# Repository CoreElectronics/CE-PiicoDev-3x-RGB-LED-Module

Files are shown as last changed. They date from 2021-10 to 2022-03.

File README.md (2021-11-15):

# PiicoDev® 3x RGB LED Module Hardware Repo


This is the repo for the Core Electronics [PiicoDev 3x RGB LED Module](https://core-electronics.com.au/catalog/product/view/sku/CE07910).

## License
This project is open source - please review the LICENSE.md file for further licensing information.

If you have any technical questions, or concerns about licensing, please contact technical support on the [Core Electronics forums](https://forum.core-electronics.com.au/).

*\"PiicoDev\" and the PiicoDev logo are trademarks of Core Electronics Pty Ltd.*

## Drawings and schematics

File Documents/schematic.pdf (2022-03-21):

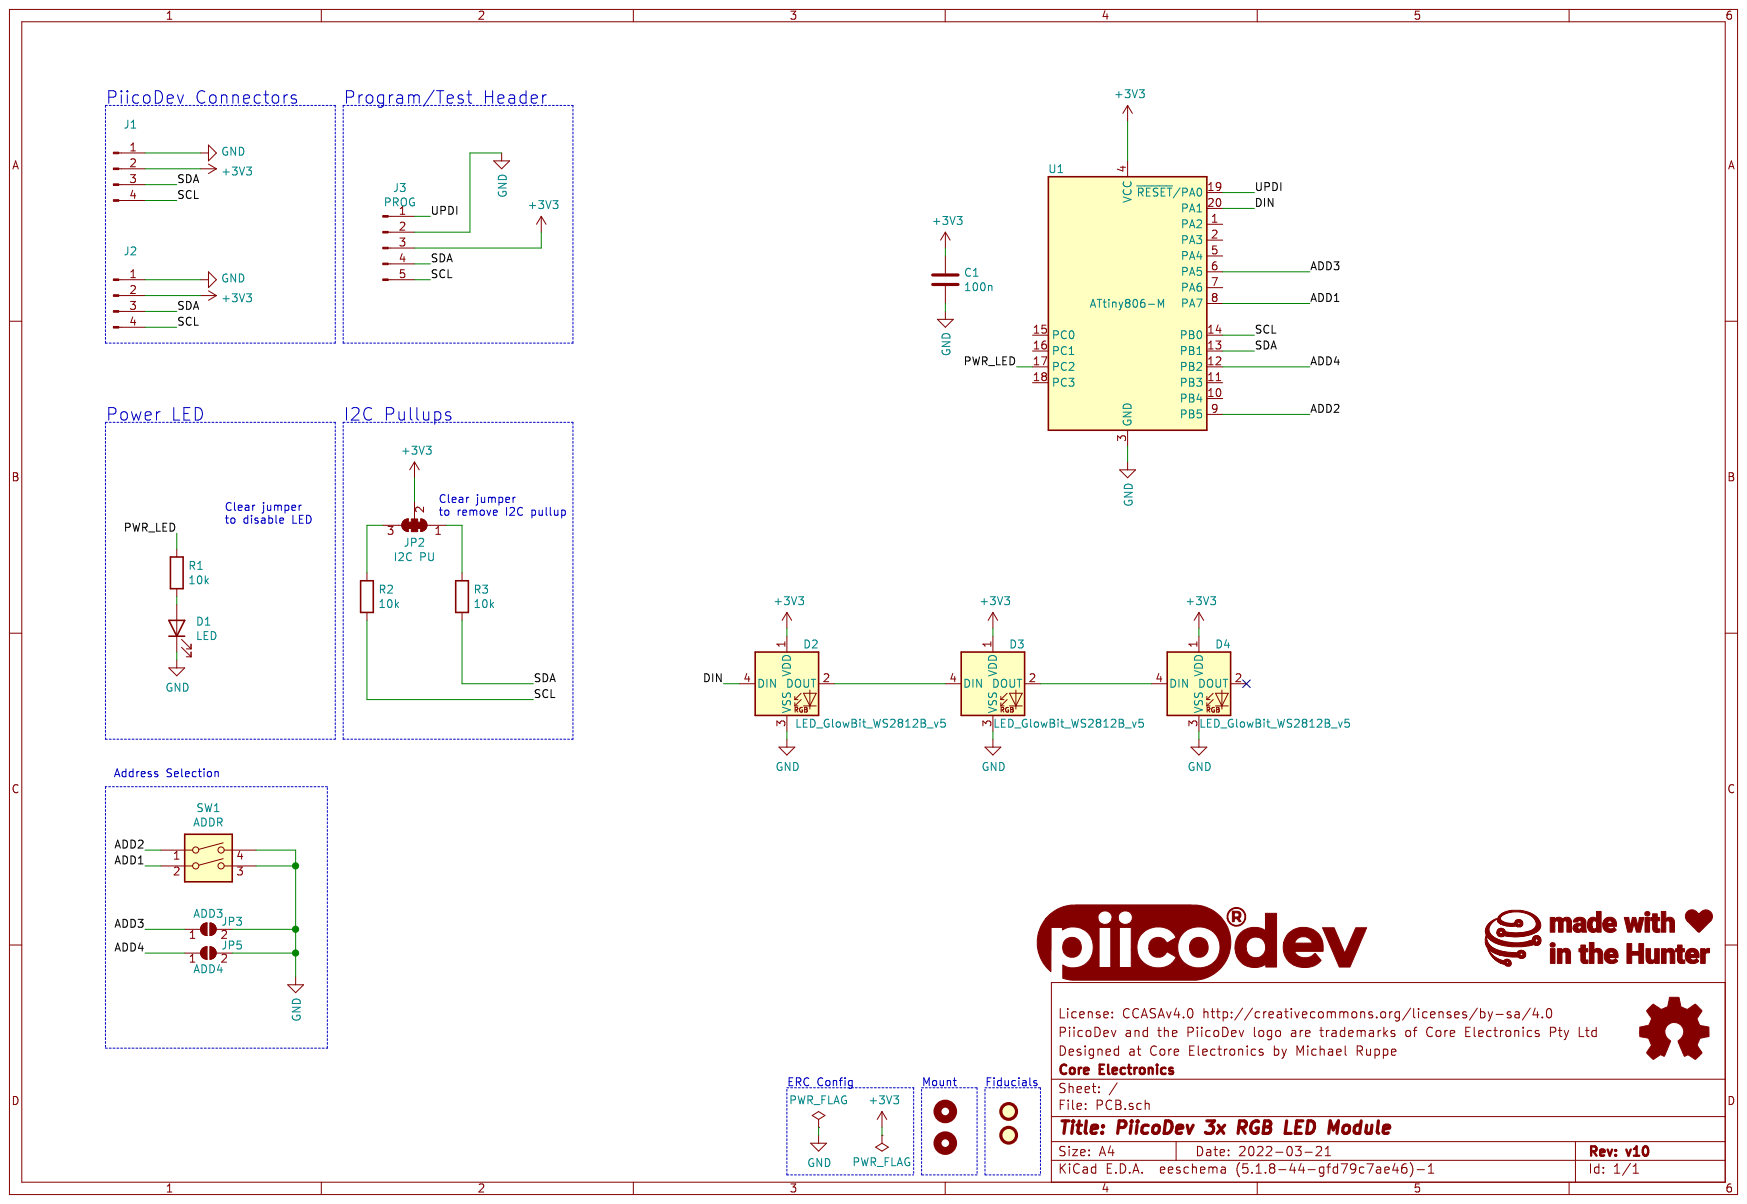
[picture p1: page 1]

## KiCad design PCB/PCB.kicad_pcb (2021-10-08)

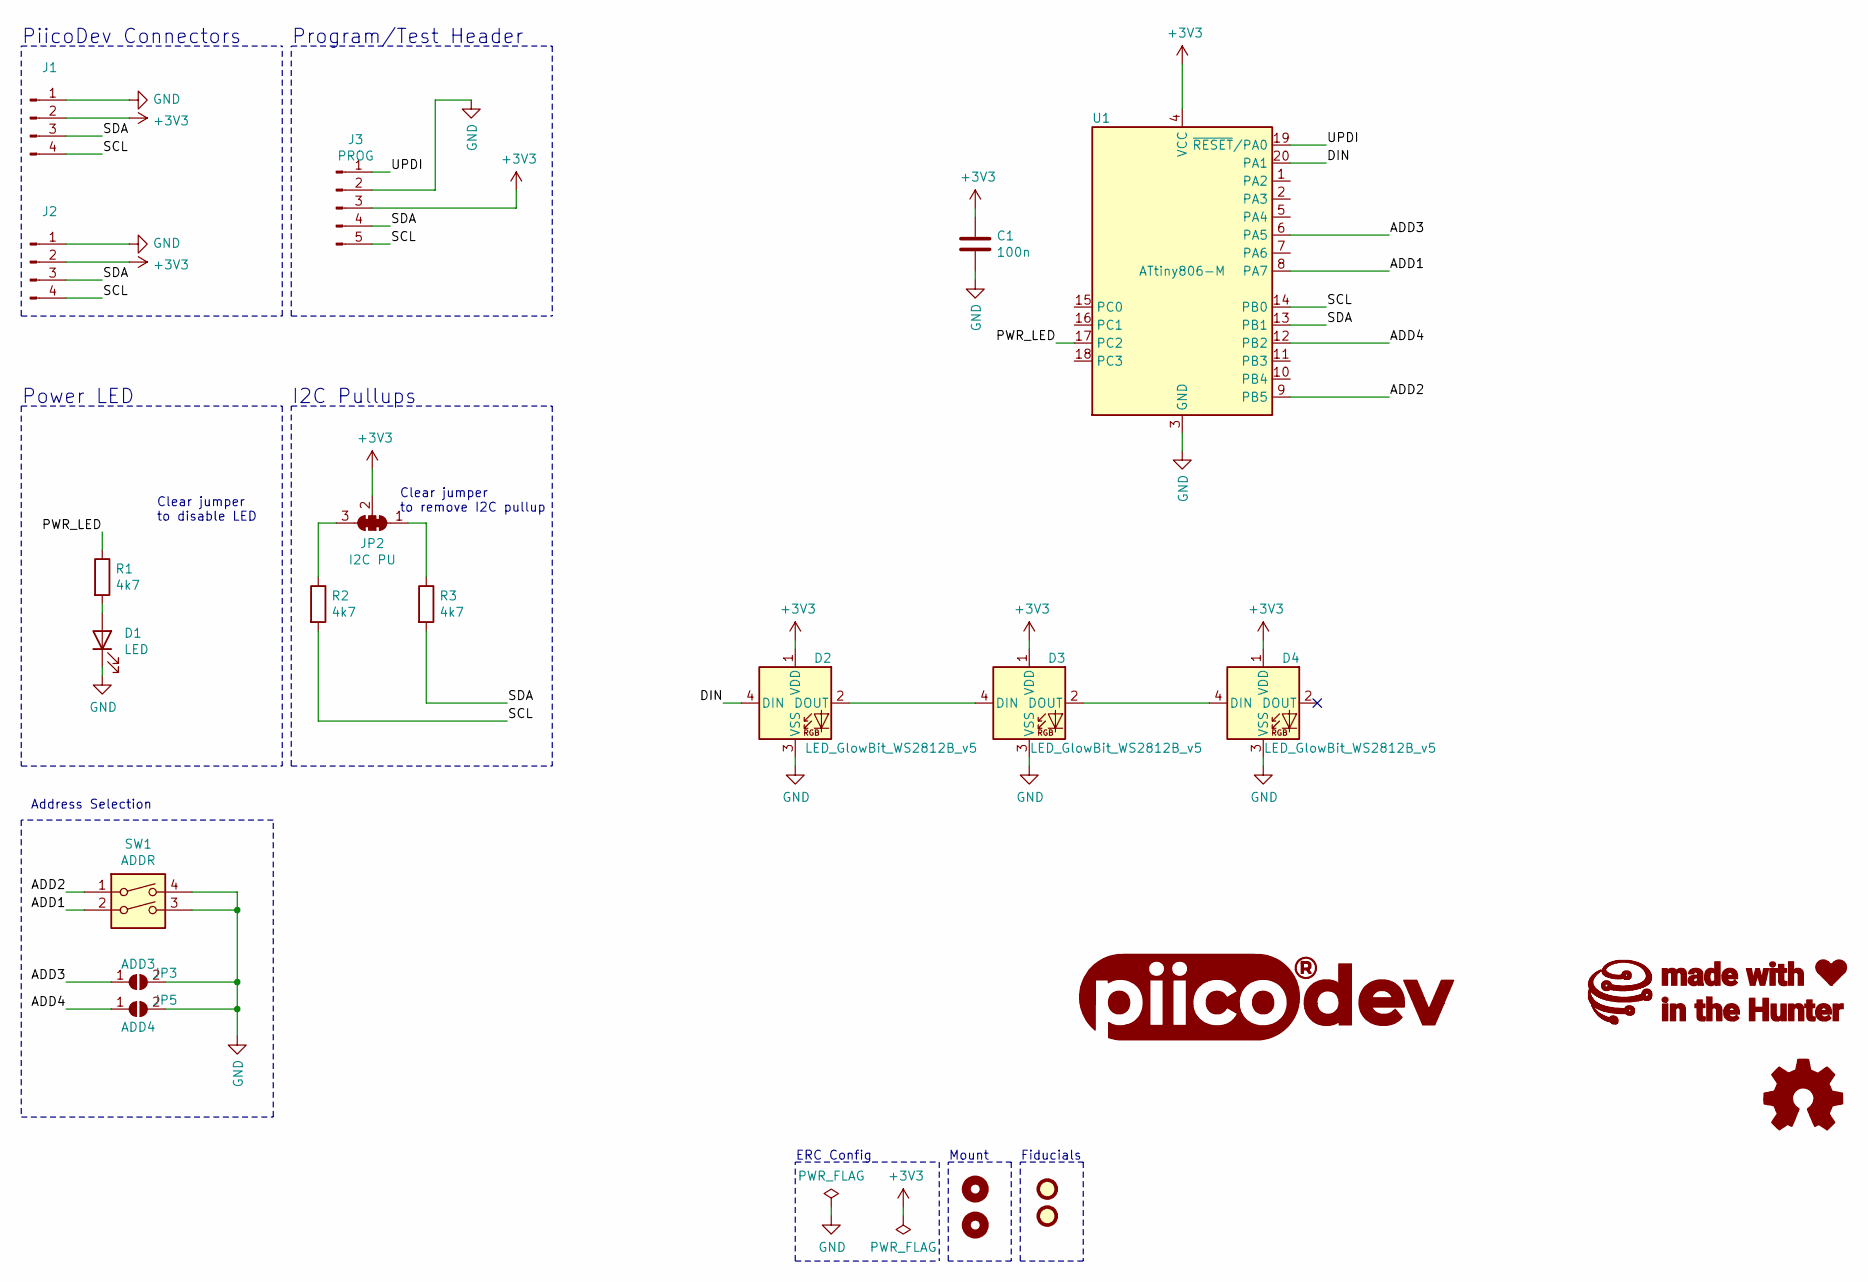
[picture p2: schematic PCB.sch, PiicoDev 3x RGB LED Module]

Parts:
C1: 100n; C_0402_1005Metric
D1: LED; LED_0603_1608Metric
D2, D3, D4: LED_GlowBit_WS2812B_v5; LED_GlowBit_WS2812B_NoSilk
FID1, FID2: Fiducial; Fiducial_1mm_Mask2mm
G1: LOGO_PiicoDev; piicodev_logo_14.2x3.4mm
G2: LOGO_CoreElectronics_no-text; CoreElectronics_logo_5mm
G3: LOGO_made-with-love; piicodev_logo_14.2x3.4mm
H1, H2: MountingHole; MountingHole_2.7mm_M2.5_PadClearance_1.2
J1, J2: JST_SH_SM04B-SRSS-TB_1x04-1MP_P1.00mm_Horizontal
J3: PROG; PiicoDev_header_programming_test_1x05_P1.27mm_Vertical
JP2: I2C PU; SolderJumper-3_P1.3mm_Closed_RoundedPad1.0x1.5mm_NumberLabe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
JP3: ADD3; SolderJumper-2_P1.3mm_Open_RoundedPad1.0x1.5mm
JP5: ADD4; SolderJumper-2_P1.3mm_Open_RoundedPad1.0x1.5mm
LOGO1: Logo_Open_Hardware_Small; oshw
R1, R2, R3: 4k7; R_0402_1005Metric
SW1: ADDR; SW_DIP_SPSTx02_Slide_DSHP
U1: ATtiny806-M; VQFN-20-1EP_3x3mm_P0.4mm_EP1.7x1.7mm

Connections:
+3V3: C1.1, D2.1 (VDD), D3.1 (VDD), D4.1 (VDD), J1.2, J2.2, J3.3, JP2.2 (C), U1.4 (VCC)
/ADD1: SW1.2, U1.8 (PA7)
/ADD2: SW1.1, U1.9 (PB5)
/ADD3: JP3.1 (A), U1.6 (PA5)
/ADD4: JP5.1 (A), U1.12 (PB2)
/DIN: D2.4 (DIN), U1.20 (PA1)
/PWR_LED: R1.1, U1.17 (PC2)
/SCL: J1.4, J2.4, J3.5, R2.2, U1.14 (PB0)
/SDA: J1.3, J2.3, J3.4, R3.2, U1.13 (PB1)
/UPDI: J3.1, U1.19 (~RESET~/PA0)
GND: C1.2, D1.1 (K), D2.3 (VSS), D3.3 (VSS), D4.3 (VSS), J1.1, J2.1, J3.2, JP3.2 (B), JP5.2 (B), SW1.3, SW1.4, U1.3 (GND), U1.21 (GND)
unnamed: D1.2 (A), R1.2
unnamed: D2.2 (DOUT), D3.4 (DIN)
unnamed: D3.2 (DOUT), D4.4 (DIN)
unnamed: JP2.1 (A), R3.1
unnamed: JP2.3 (B), R2.1

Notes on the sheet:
ERC Config
Fiducials
Mount
PiicoDev Connectors
Program/Test Header
Clear jumper to remove I2C pullup
I2C Pullups
Power LED
Clear jumper to disable LED
Address Selection

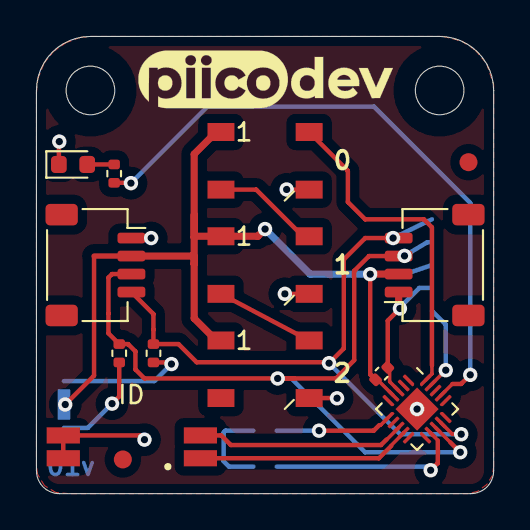
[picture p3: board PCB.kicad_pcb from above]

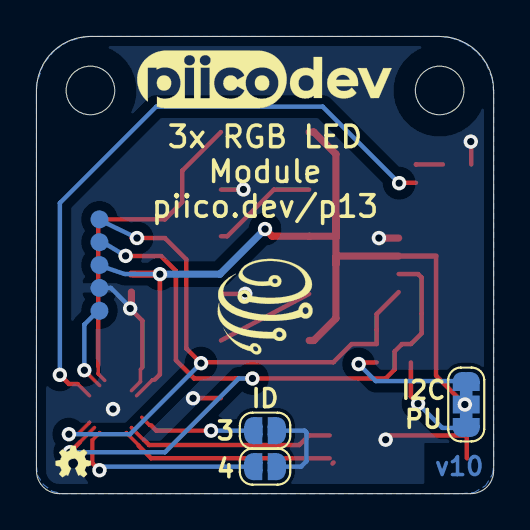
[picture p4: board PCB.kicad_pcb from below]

Board: 2 copper layers, 25.4 x 25.4 mm, 24 parts (7 on the bottom side), 16 nets.

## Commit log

2021-08-26 Make pwr LED user controllable
    [PCB.kicad_pcb, PCB.sch]
2021-10-08 rotate ID switch
    [PCB.kicad_pcb, PCB.sch]
2022-03-21 update resistors to 10k, add schematic
    [PCB.sch]
2022-03-21 update title block
    [PCB.sch]
